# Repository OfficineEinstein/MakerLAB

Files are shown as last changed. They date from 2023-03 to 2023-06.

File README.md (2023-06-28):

# MakerLAB
Demo board didattica per i laboratori di Tecnologie e Progettazione di Sistemi Elettronici (TPSE):  elettronica digitale e microcontrollori
 
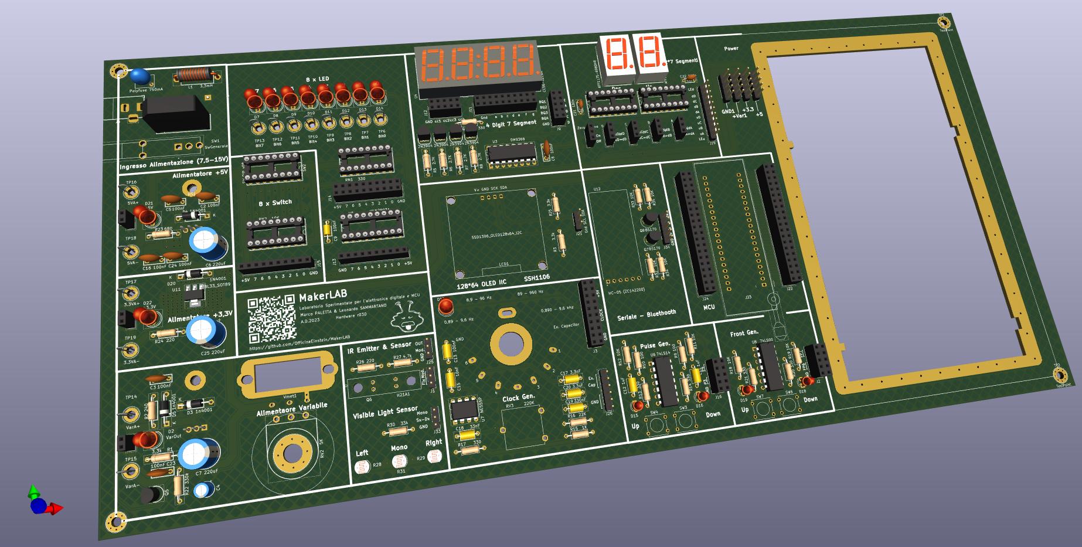
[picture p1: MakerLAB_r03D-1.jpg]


Il laboratorio portatile finalmente operativo
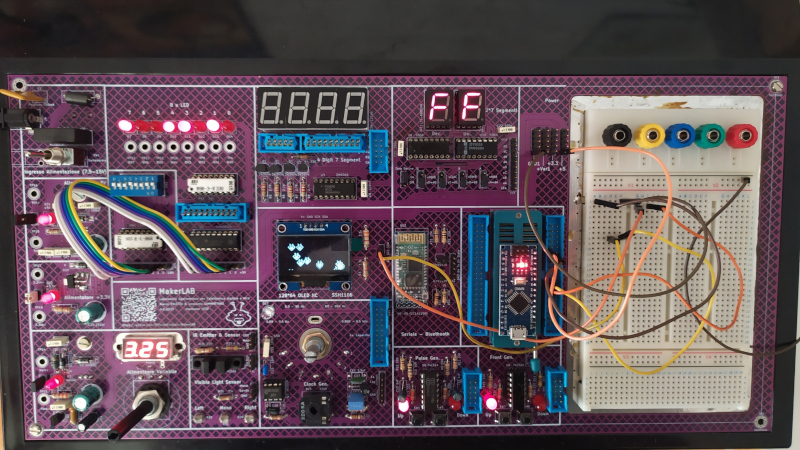
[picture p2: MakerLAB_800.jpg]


Video testing of the MakerLAB

[](https://www.youtube.com/watch?v=5uMLk8OzwR4 "videoprova shield")

https://youtu.be/5uMLk8OzwR4

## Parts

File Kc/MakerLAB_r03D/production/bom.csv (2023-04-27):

Designator | Footprint | Quantity | Value | LCSC Part #
+3.3, +5, +Var1, GND1, J34 | PinHeader_1x05_P2.54mm_Vertical | 5 | Conn_01x05
AFF1, AFF2 | 7SegmentLED_LTS6760_LTS6780 | 2 | LTS-6980HR
C1 | CP_Radial_D17.0mm_P7.50mm | 1 | 1000uF
C11, C12 | C_Axial_L5.1mm_D3.1mm_P7.50mm_Horizontal | 2 | 1uF
C13 | C_Axial_L5.1mm_D3.1mm_P7.50mm_Horizontal | 1 | 100nF
C15 | C_Axial_L5.1mm_D3.1mm_P7.50mm_Horizontal | 1 | 10nF
C16, C2, C23, C24, C3, C5 | C_Disc_D7.0mm_W2.5mm_P5.00mm | 6 | 100nF
C17 | C_Axial_L5.1mm_D3.1mm_P7.50mm_Horizontal | 1 | 3,3nF
C18 | C_Axial_L5.1mm_D3.1mm_P7.50mm_Horizontal | 1 | 33nF
C19 | C_Axial_L5.1mm_D3.1mm_P7.50mm_Horizontal | 1 | 330nF
C20 | C_Axial_L5.1mm_D3.1mm_P7.50mm_Horizontal | 1 | 3,3uF
C21, C22 | C_Disc_D4.3mm_W1.9mm_P5.00mm | 2 | 100n
C25, C6, C7 | CP_Radial_D10.0mm_P5.00mm | 3 | 220uF
C4 | CP_Radial_D5.0mm_P2.00mm | 1 | 10uF
C8 | C_Disc_D7.5mm_W2.5mm_P5.00mm | 1 | 100nF
C9 | C_Axial_L3.8mm_D2.6mm_P7.50mm_Horizontal | 1 | 100nF
D1 | Diode_Bridge_Vishay_KBL | 1 | D_Bridge_+AA-
D10 | LED_D5.0mm | 1 | 4
D11 | LED_D5.0mm | 1 | 3
D12 | LED_D5.0mm | 1 | 2
D13 | LED_D5.0mm | 1 | 1
D14 | LED_D5.0mm | 1 | 0
D15, D16, D18, D19 | LED_D3.0mm | 4 | LED
D17 | LED_D5.0mm | 1 | LED
D2 | LED_D5.0mm | 1 | VarOut
D20, D3, D4, D5 | D_A-405_P10.16mm_Horizontal | 4 | 1N4001
D21 | LED_D5.0mm | 1 | +5V
D22 | LED_D5.0mm | 1 | +3.3V
D7 | LED_D5.0mm | 1 | 7
D8 | LED_D5.0mm | 1 | 6
D9 | LED_D5.0mm | 1 | 5
F1 | RV_Disc_D7mm_W5.4mm_P5mm | 1 | Polyfuse 750mA
HS1, HS2 | Heatsink_28x25_Horiz | 2 | Heatsink
J1 | PinHeader_1x03_P2.54mm_Vertical | 1 | Fix
J11 | PinSocket_2x10_P2.54mm_Vertical | 1 | Gnd a b c d e f g
J12 | PinSocket_2x05_P2.54mm_Vertical | 1 | GND cc1 cc2
J13 | PinSocket_1x10_P2.54mm_Vertical | 1 | GND 7 6 5 4 3 2 1 0 +5V
J14 | PinSocket_2x10_P2.54mm_Vertical | 1 | +5V 7 6 5 4 3 2 1 0 GND
J15 | PinSocket_1x10_P2.54mm_Vertical | 1 | +5V 7 6 5 4 3 2 1 0 GND
J16 | PinSocket_2x05_P2.54mm_Vertical | 1 | P3 P4
J19 | PinHeader_1x10_P2.54mm_Vertical | 1 | LeU A0 A1 A2 A3 A0 A1 A2 A3 LeD
J2 | PinSocket_2x05_P2.54mm_Vertical | 1 | FP6 FP7
J21 | PinHeader_1x03_P2.54mm_Vertical | 1 | Gnd SCL SDA
J22, J24 | PinSocket_2x20_P2.54mm_Vertical | 2 | Conn_02x20_Counter_Clockwise
J23 | DIP_Socket-40_W22.1_W22.86_W25.4_W27.94_W28.7_3M_240-3639-00-0602J | 1 | 1
J25 | PinHeader_1x03_P2.54mm_Vertical | 1 | IR Emitter & Sensor
J26 | PinHeader_1x06_P2.54mm_Vertical | 1 | Conn_01x06_Female
J29, J30, J5 | PinSocket_1x02_P2.54mm_Vertical | 3 | Conn_01x02_Male
J3 | PinSocket_2x10_P2.54mm_Vertical | 1 | GND CLOCK +5V
J33 | PinHeader_1x03_P2.54mm_Vertical | 1 | Visible Light Sensor
J4 | BarrelJack_Horizontal | 1 | Barrel_Jack_MountingPin
J9 | PinSocket_2x05_P2.54mm_Vertical | 1 | A B C D LE
L1 | L_Axial_L12.0mm_D5.0mm_P15.24mm_Horizontal_Fastron_MISC | 1 | 3,3mH
LCD1 | TFT OLED 1.3 I2C | 1 | SSD1306_OLED128x64_I2C
Q1, Q2, Q3, Q4 | TO-92_Inline | 4 | 2N3904
Q5 | TO-92_Inline | 1 | BC237
Q6 | H21A1 | 1 | H21A1
Q7, Q8 | TO-92_Inline | 2 | BS170
R1, R25, R3 | R_Axial_DIN0207_L6.3mm_D2.5mm_P10.16mm_Horizontal | 3 | 3,3k
R10, R9 | R_Axial_DIN0207_L6.3mm_D2.5mm_P10.16mm_Horizontal | 2 | 100
R11, R12, R18, R19, R32, R33, R34, R35 | R_Axial_DIN0207_L6.3mm_D2.5mm_P10.16mm_Horizontal | 8 | 10K
R13, R14, R17, R20, R21, R4 | R_Axial_DIN0207_L6.3mm_D2.5mm_P10.16mm_Horizontal | 6 | 330
R15 | R_Axial_DIN0207_L6.3mm_D2.5mm_P10.16mm_Horizontal | 1 | 1K
R16 | R_Axial_DIN0207_L6.3mm_D2.5mm_P10.16mm_Horizontal | 1 | 22K
R2 | R_Axial_DIN0207_L6.3mm_D2.5mm_P10.16mm_Horizontal | 1 | 240
R22 | R_Axial_DIN0207_L6.3mm_D2.5mm_P10.16mm_Horizontal | 1 | 330k
R23 | R_Axial_DIN0207_L6.3mm_D2.5mm_P10.16mm_Horizontal | 1 | 680
R24, R26 | R_Axial_DIN0207_L6.3mm_D2.5mm_P10.16mm_Horizontal | 2 | 220
R27 | R_Axial_DIN0207_L6.3mm_D2.5mm_P10.16mm_Horizontal | 1 | 4,7k
R28 | R_LDR_5.0x4.1mm_P3mm_Vertical | 1 | Left
R29 | R_LDR_5.0x4.1mm_P3mm_Vertical | 1 | Right
R30 | R_Axial_DIN0207_L6.3mm_D2.5mm_P10.16mm_Horizontal | 1 | 33k
R31 | R_LDR_5.0x4.1mm_P3mm_Vertical | 1 | Mono
R5, R6, R7, R8 | R_Axial_DIN0207_L6.3mm_D2.5mm_P10.16mm_Horizontal | 4 | 2.7K
RN1 | DIP-16_W7.62mm_Socket_LongPads | 1 | 330
RN2 | DIP-16_W7.62mm_Socket_LongPads | 1 | 10K
RV2 | Potentiometer_Omeg_PC16BU_Vertical | 1 | 5K
RV3 | Potentiometer_ACP_CA14V-15_Vertical | 1 | 220K
SW1 | SW_100SP1T2B4M7QE | 1 | SwGenerale
SW2 | DIP-16_W7.62mm_Socket_LongPads | 1 | SW_DIP_x08
SW3, SW6 | SW_Tactile_Straight_KSL0Axx1LFTR | 2 | Down
SW4, SW7 | SW_Tactile_Straight_KSL0Axx1LFTR | 2 | Up
SW5 | Commutatore 2x6 | 1 | SW_Rotary12
TP1, TP2, TP3, TP4 | MountingHole_3.2mm_M3_Pad_Via | 4 | TestPoint
TP10 | TestPoint_Loop_D3.80mm_Drill2.8mm | 1 | Bit4
TP11 | TestPoint_Loop_D3.80mm_Drill2.8mm | 1 | Bit5
TP12 | TestPoint_Loop_D3.80mm_Drill2.8mm | 1 | Bit6
TP13 | TestPoint_Loop_D3.80mm_Drill2.8mm | 1 | Bit7
TP14 | TestPoint_Loop_D3.80mm_Drill2.8mm | 1 | VarA+
TP15 | TestPoint_Loop_D3.80mm_Drill2.8mm | 1 | VarA-
TP16 | TestPoint_Loop_D3.80mm_Drill2.8mm | 1 | 5VA+
TP17 | TestPoint_Loop_D3.80mm_Drill2.8mm | 1 | 3.3VA+
TP18 | TestPoint_Loop_D3.80mm_Drill2.8mm | 1 | 5VA-
TP19 | TestPoint_Loop_D3.80mm_Drill2.8mm | 1 | 3.3VA-
TP20 | MountingHole_6.5mm_Pad_Via | 1 | Potenziometer
TP21 | Alimentatore Variabile | 1 | Alimentaore Variabile
TP22 | Alimentatore Variabile | 1 | Alimentatore +3,3V
TP23 | Alimentatore Variabile | 1 | Alimentatore +5V
TP24 | Alimentatore Variabile | 1 | Ingresso Alimentazione (7,5-15V)
TP25 | Alimentatore Variabile | 1 | 8 x Switch
TP26 | Alimentatore Variabile | 1 | 8 x LED
TP27 | Disp4x7Seg | 1 | 8 x LED
TP28 | MakerLABTitoli | 1 | MakerLAB
TP29 | Clock NE555 | 1 | Clock Gen.
TP31, TP32, TP35 | Disp4x7Seg | 3 | Pulse Generator
TP34 | Disp4x7Seg | 1 | 2*7 Segmenti
TP5 | BreadBoard 81x146 | 1 | TestPoint
TP6 | TestPoint_Loop_D3.80mm_Drill2.8mm | 1 | Bit0
TP7 | TestPoint_Loop_D3.80mm_Drill2.8mm | 1 | Bit1
TP8 | TestPoint_Loop_D3.80mm_Drill2.8mm | 1 | Bit2
TP9 | TestPoint_Loop_D3.80mm_Drill2.8mm | 1 | Bit3
U1 | TO-220-3_Horizontal_TabDown | 1 | LM317_TO-220
U10, U9 | DIP-16_W7.62mm_Socket_LongPads | 2 | 9368
U11 | SOT-223 | 1 | L78L33_SOT89
U12 | HC-05 Module Horizontal (ZC14200) | 1 | HC-05 (ZC142200)
U2 | TO-220-3_Horizontal_TabDown | 1 | LM7805_TO220
U3 | DIP-16_W7.62mm_LongPads | 1 | DM9368
U4 | CA56-12EWA | 1 | CC56-12EWA
U5 | DIP-18_W7.62mm_Socket_LongPads | 1 | ULN2803A
U6 | DIP-14_W7.62mm | 1 | 74LS14
U7 | DIP-8_W7.62mm | 1 | NE555P
U8 | DIP-14_W7.62mm | 1 | 74LS00
Uni-A0, Uni-A1, Uni-A2, Uni-A3 | PinSocket_1x03_P2.54mm_Vertical | 4 | Jumper_3_Open
Uni-A4 | PinSocket_1x03_P2.54mm_Vertical | 1 | Zero Decine
Vmet1 | 3,5 Digit 0,28'' Voltmeter | 1 | 3,5_Digit_Voltmeter_3Wire

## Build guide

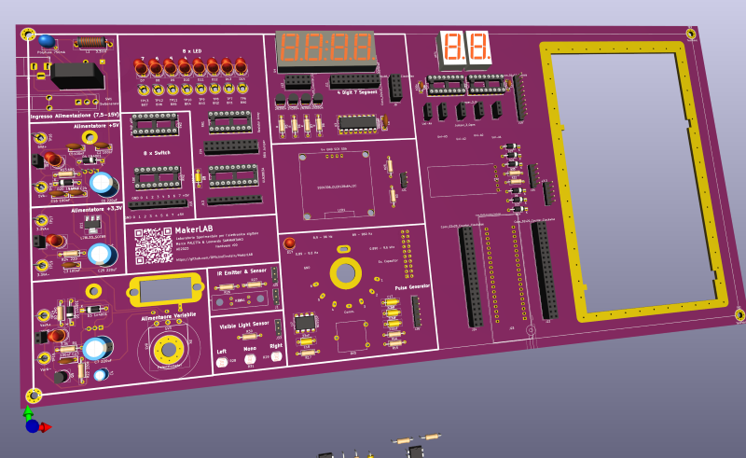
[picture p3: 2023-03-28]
MakerLAB_800.png

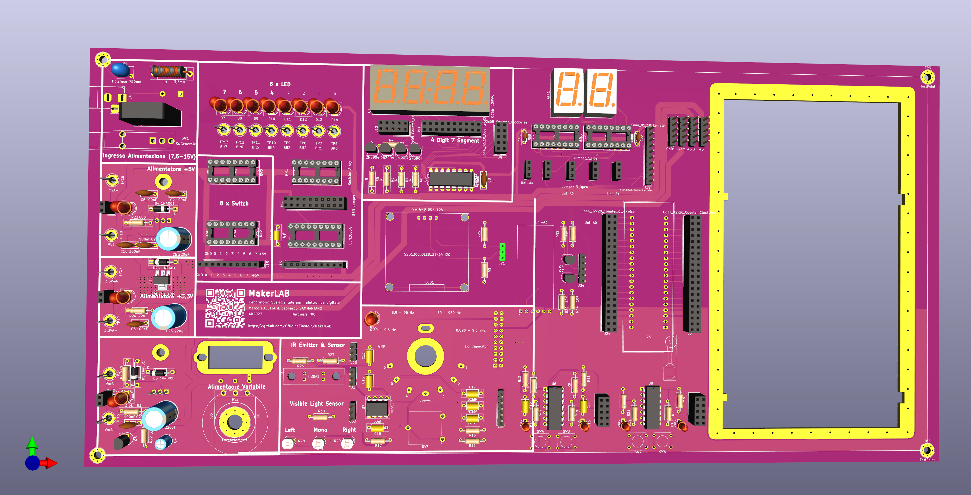
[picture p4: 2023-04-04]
Kc/MakerLAB_r03D1/MakerLAB_r03D1.png

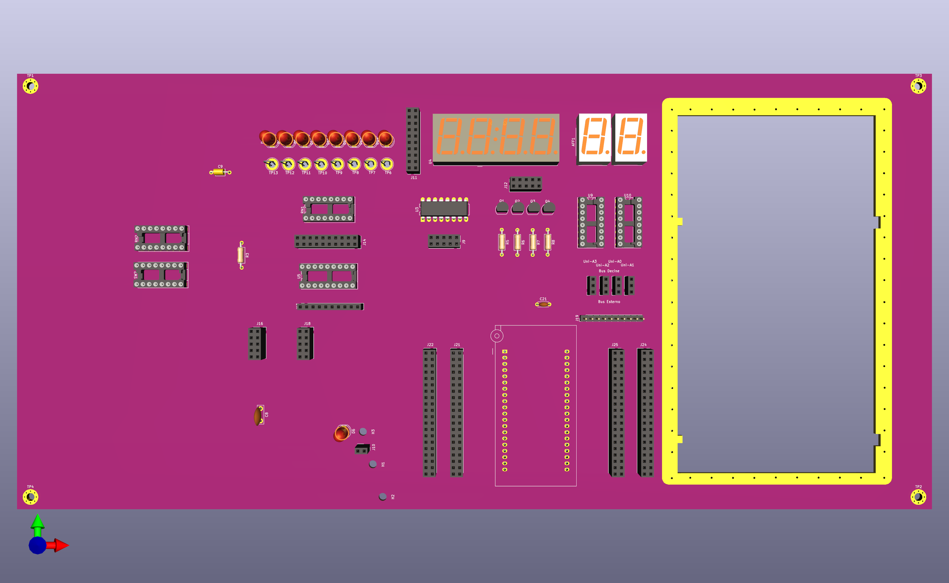
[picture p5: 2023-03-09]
Kc/MakerLAB_r03D1/MakerLab_r02-Incoming00.png

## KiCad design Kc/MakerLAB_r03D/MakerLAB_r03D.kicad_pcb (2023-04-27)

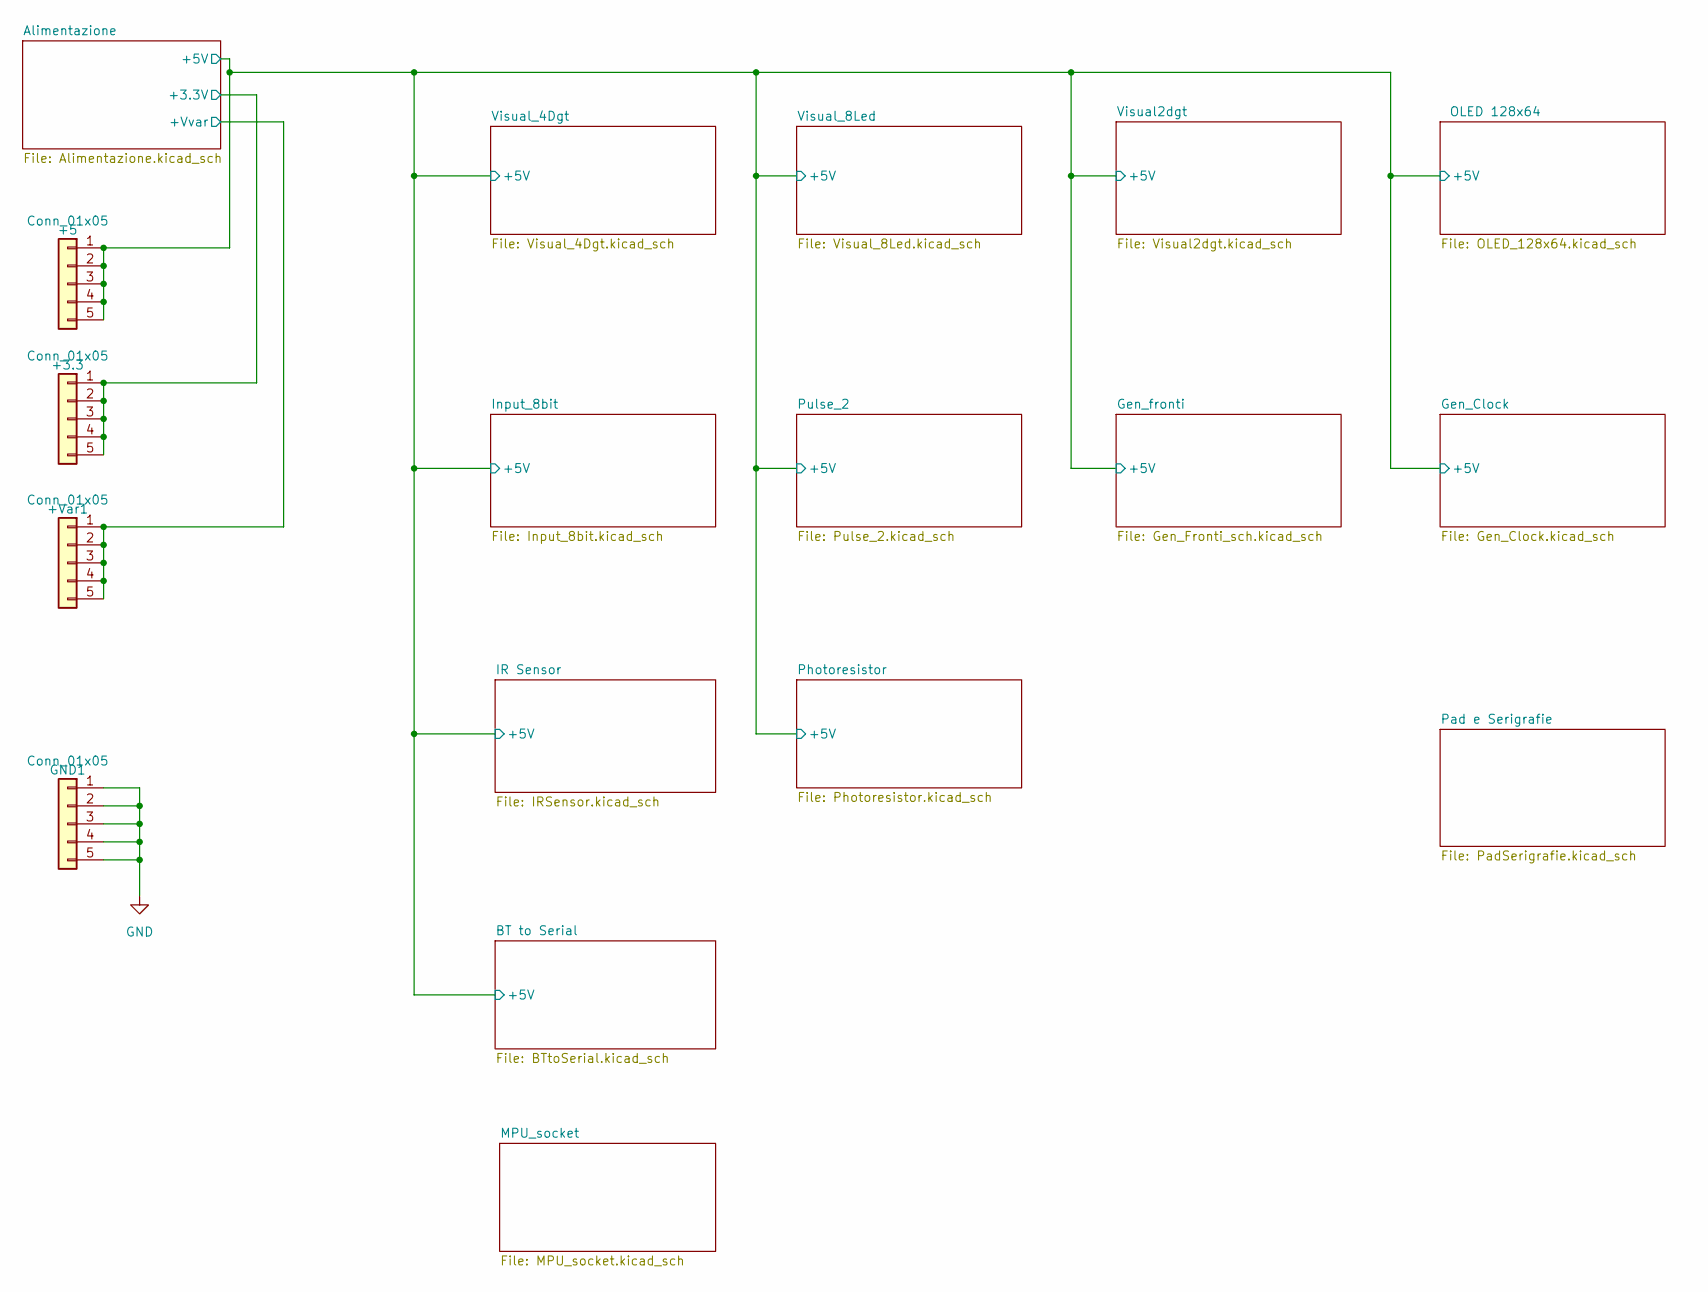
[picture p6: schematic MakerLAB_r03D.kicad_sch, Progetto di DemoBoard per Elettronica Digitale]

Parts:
+3.3, +5: Conn_01x05; PinHeader_1x05_P2.54mm_Vertical
+Var1: Conn_01x05; PinHeader_1x05_P2.54mm_Vertical
GND1: Conn_01x05; PinHeader_1x05_P2.54mm_Vertical

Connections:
/Alimentazione/+3.3V: +3.3.1, +3.3.2, +3.3.3, +3.3.4, +3.3.5; also elsewhere on the board
/Alimentazione/+5V: +5.1, +5.2, +5.3, +5.4, +5.5; also elsewhere on the board
/Alimentazione/+Vvar: +Var1.1, +Var1.2, +Var1.3, +Var1.4, +Var1.5; also elsewhere on the board

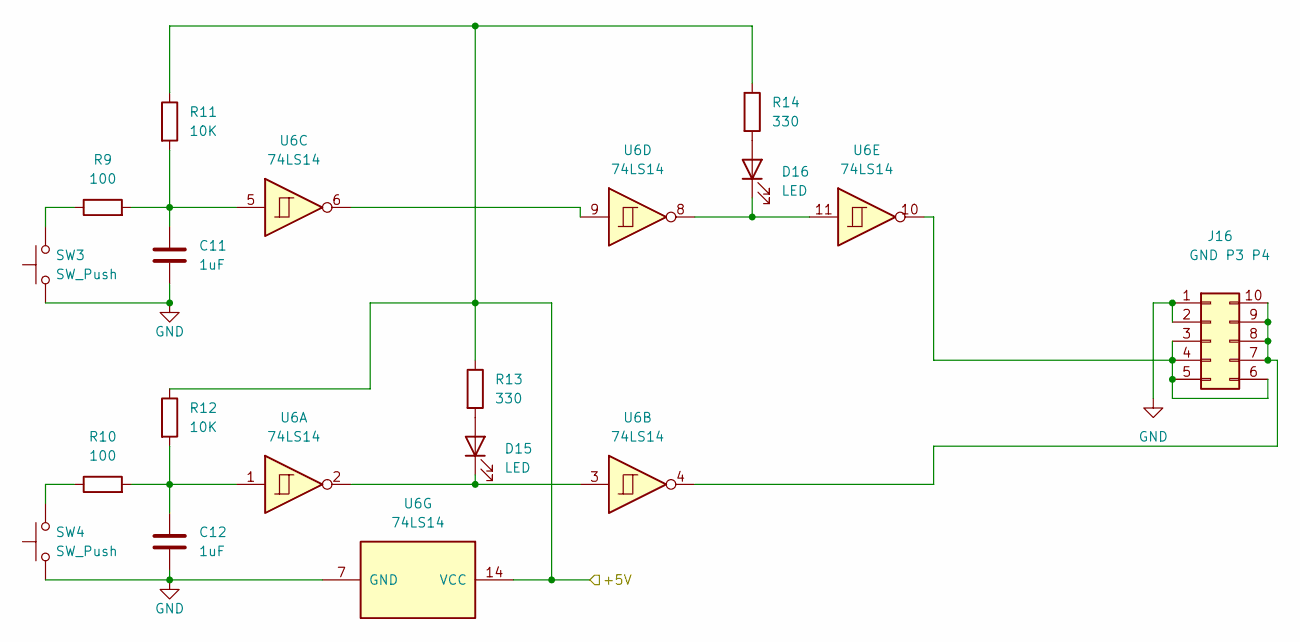
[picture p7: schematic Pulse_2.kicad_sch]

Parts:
C11, C12: 1uF; C_Axial_L5.1mm_D3.1mm_P7.50mm_Horizontal
D15, D16: LED; LED_D3.0mm
J16: GND P3 P4; PinSocket_2x05_P2.54mm_Vertical
R9, R10: 100; R_Axial_DIN0207_L6.3mm_D2.5mm_P10.16mm_Horizontal
R11, R12: 10K; R_Axial_DIN0207_L6.3mm_D2.5mm_P10.16mm_Horizontal
R13, R14: 330; R_Axial_DIN0207_L6.3mm_D2.5mm_P10.16mm_Horizontal
SW3, SW4: SW_Push; SW_Tactile_Straight_KSL0Axx1LFTR
U6: 74LS14; DIP-14_W7.62mm

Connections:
/Alimentazione/+5V: R11.1, R12.1, R13.1, R14.1, U6.14 (VCC); also elsewhere on the board
unnamed: C11.1, R9.2, R11.2, U6.5
unnamed: C12.1, R10.2, R12.2, U6.1
unnamed: D15.1 (K), U6.2, U6.3
unnamed: D15.2 (A), R13.2
unnamed: D16.1 (K), U6.8, U6.11
unnamed: D16.2 (A), R14.2
unnamed: J16.3, J16.4, J16.5, J16.6, U6.10
unnamed: J16.7, J16.8, J16.9, J16.10, U6.4
unnamed: R9.1, SW3.2
unnamed: R10.1, SW4.2
unnamed: U6.6, U6.9

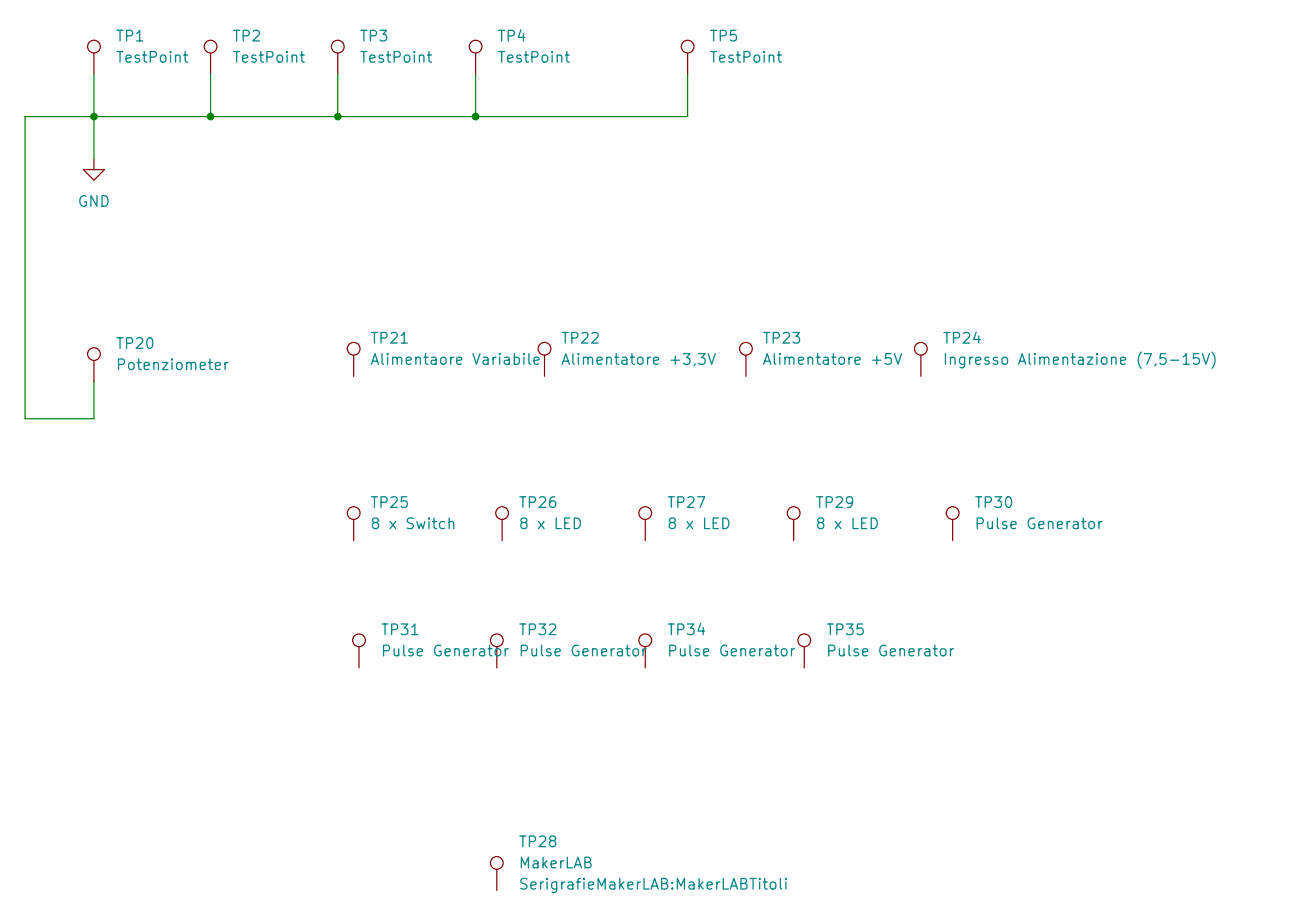
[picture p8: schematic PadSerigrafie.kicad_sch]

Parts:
TP1, TP2, TP3, TP4: TestPoint; MountingHole_3.2mm_M3_Pad_Via
TP5: TestPoint; BreadBoard 81x146
TP20: Potenziometer; MountingHole_6.5mm_Pad_Via
TP21: Alimentaore Variabile; Alimentatore Variabile
TP22: Alimentatore +3,3V; Alimentatore Variabile
TP23: Alimentatore +5V; Alimentatore Variabile
TP24: Ingresso Alimentazione (7,5-15V); Alimentatore Variabile
TP25: 8 x Switch; Alimentatore Variabile
TP26: 8 x LED; Alimentatore Variabile
TP27: 8 x LED; Disp4x7Seg
TP28: MakerLAB; MakerLABTitoli
TP29: 8 x LED; Clock NE555
TP30: Pulse Generator; Clock NE555
TP31, TP32, TP34, TP35: Pulse Generator; Disp4x7Seg

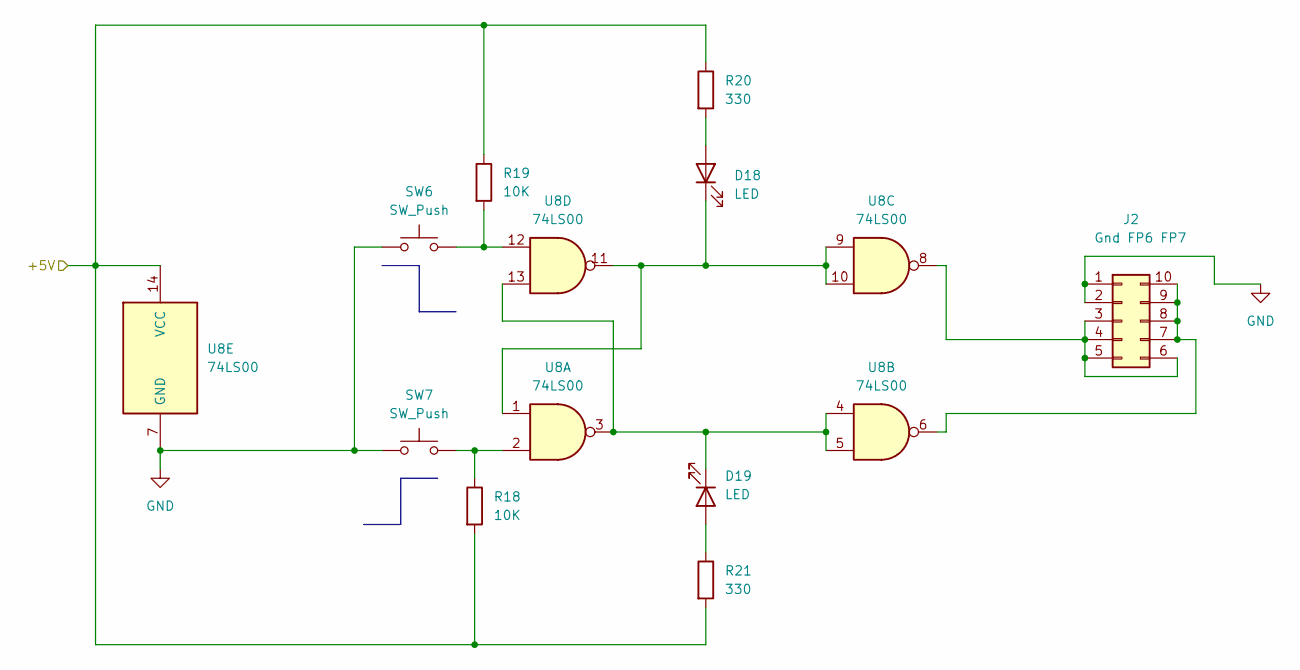
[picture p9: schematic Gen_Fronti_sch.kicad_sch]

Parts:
D18, D19: LED; LED_D3.0mm
J2: Gnd FP6 FP7; PinSocket_2x05_P2.54mm_Vertical
R18, R19: 10K; R_Axial_DIN0207_L6.3mm_D2.5mm_P10.16mm_Horizontal
R20, R21: 330; R_Axial_DIN0207_L6.3mm_D2.5mm_P10.16mm_Horizontal
SW6, SW7: SW_Push; SW_Tactile_Straight_KSL0Axx1LFTR
U8: 74LS00; DIP-14_W7.62mm

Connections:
/Alimentazione/+5V: R18.2, R19.1, R20.1, R21.2, U8.14 (VCC); also elsewhere on the board
unnamed: D18.1 (K), U8.1, U8.9, U8.10, U8.11
unnamed: D18.2 (A), R20.2
unnamed: D19.1 (K), U8.3, U8.4, U8.5, U8.13
unnamed: D19.2 (A), R21.1
unnamed: J2.3, J2.4, J2.5, J2.6, U8.8
unnamed: J2.7, J2.8, J2.9, J2.10, U8.6
unnamed: R18.1, SW7.2, U8.2
unnamed: R19.2, SW6.2, U8.12

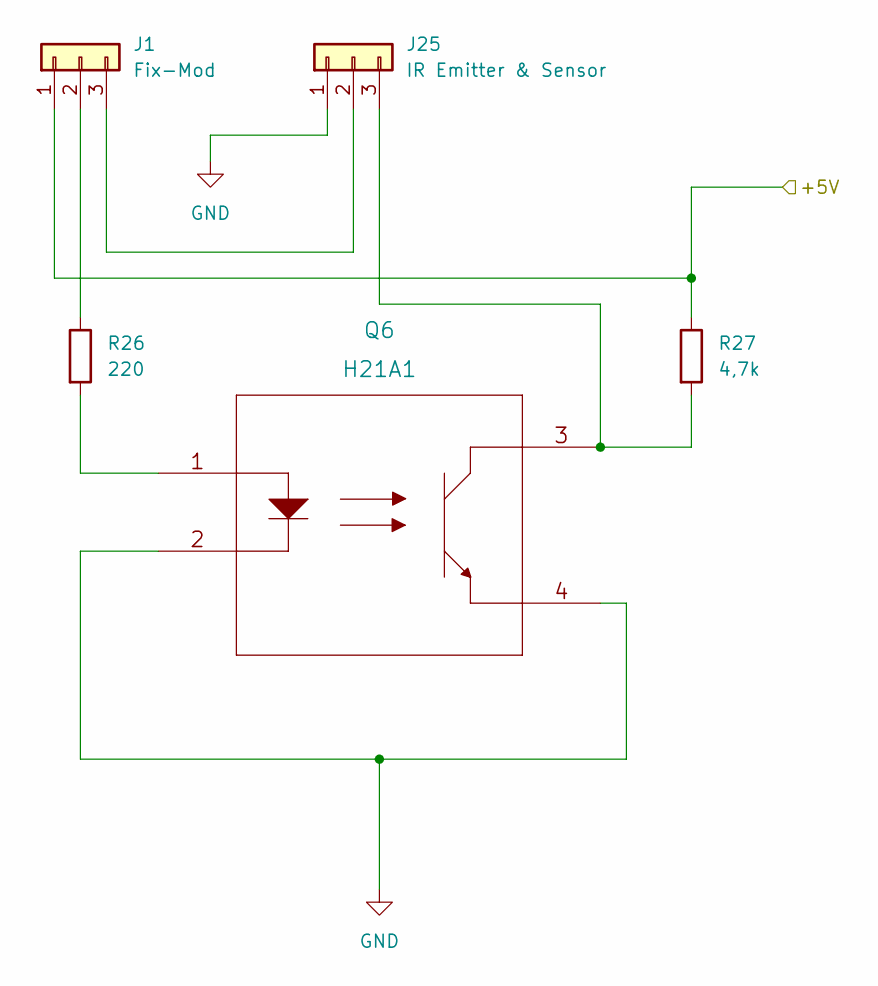
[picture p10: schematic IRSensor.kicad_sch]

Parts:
J1: Fix-Mod; PinHeader_1x03_P2.54mm_Vertical
J25: IR Emitter & Sensor; PinHeader_1x03_P2.54mm_Vertical
Q6: H21A1
R26: 220; R_Axial_DIN0207_L6.3mm_D2.5mm_P10.16mm_Horizontal
R27: 4,7k; R_Axial_DIN0207_L6.3mm_D2.5mm_P10.16mm_Horizontal

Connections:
/Alimentazione/+5V: J1.1, R27.1; also elsewhere on the board
unnamed: J1.2, R26.1
unnamed: J1.3, J25.2
unnamed: J25.3, Q6.3, R27.2
unnamed: Q6.1, R26.2

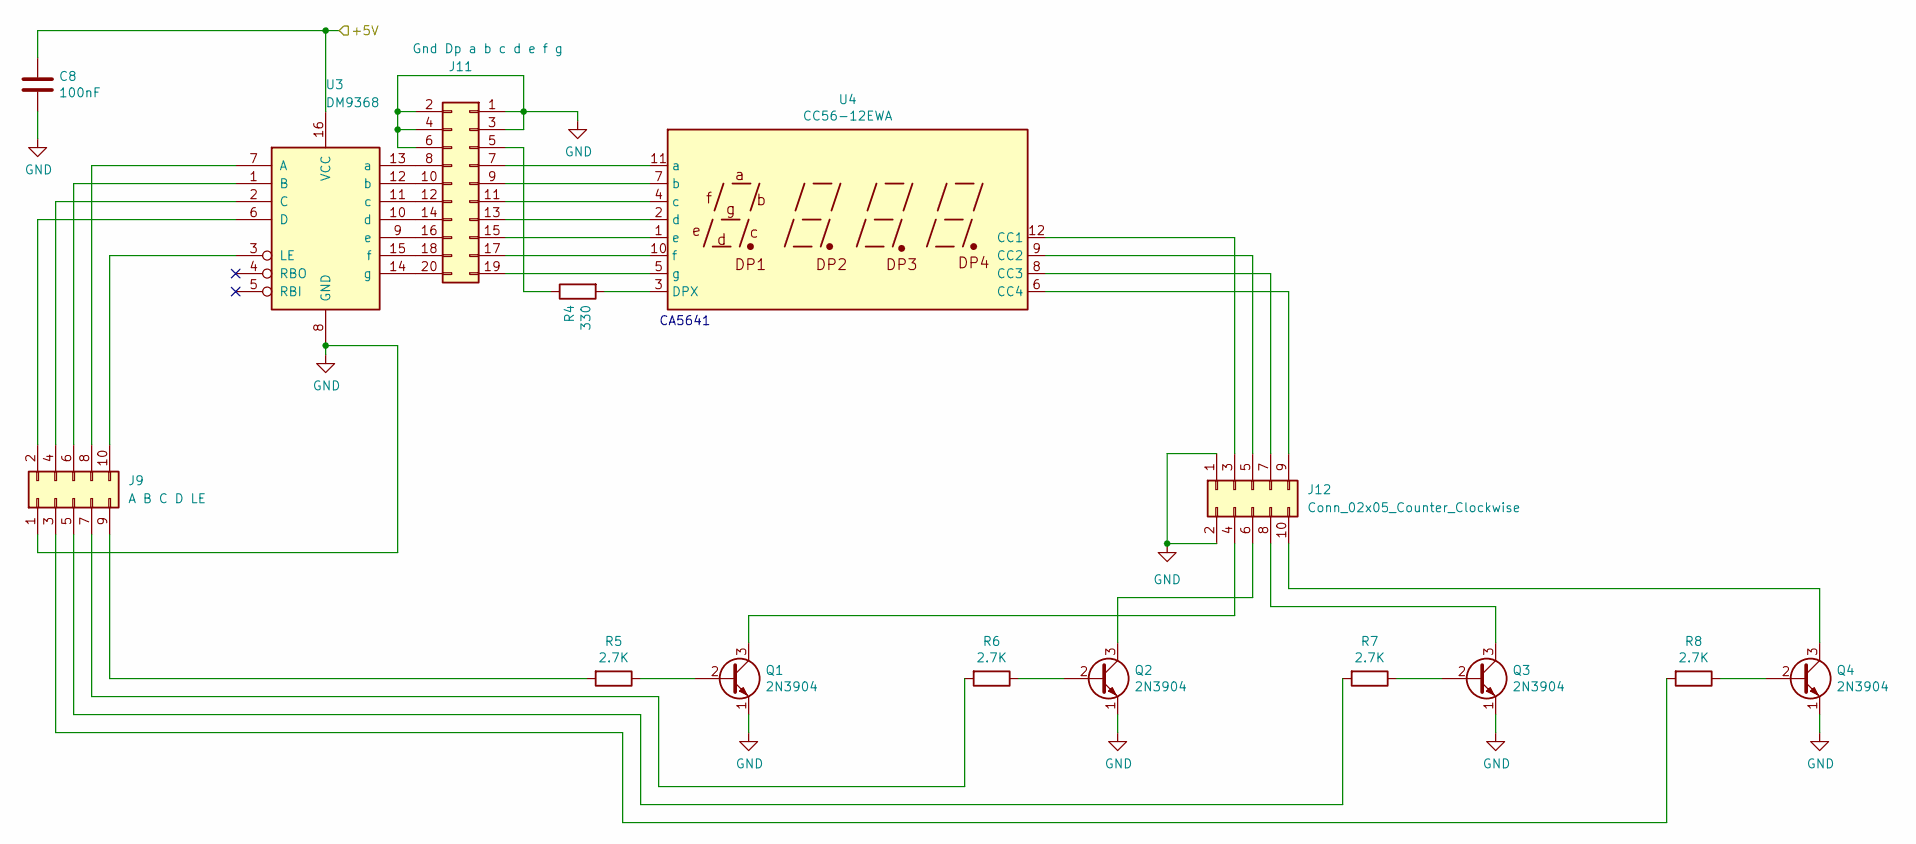
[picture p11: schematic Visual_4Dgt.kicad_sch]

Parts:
C8: 100nF; C_Disc_D7.5mm_W2.5mm_P5.00mm
J9: A B C D LE; PinSocket_2x05_P2.54mm_Vertical
J11: Gnd Dp a b c d e f g; PinSocket_2x10_P2.54mm_Vertical
J12: Conn_02x05_Counter_Clockwise; PinSocket_2x05_P2.54mm_Vertical
Q1, Q2, Q3, Q4: 2N3904; TO-92_Inline
R4: 330; R_Axial_DIN0207_L6.3mm_D2.5mm_P10.16mm_Horizontal
R5, R6, R7, R8: 2.7K; R_Axial_DIN0207_L6.3mm_D2.5mm_P10.16mm_Horizontal
U3: DM9368; DIP-16_W7.62mm_LongPads
U4: CC56-12EWA; CA56-12EWA

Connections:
/Alimentazione/+5V: C8.1, U3.16 (VCC); also elsewhere on the board
unnamed: J9.2, U3.6 (D)
unnamed: J9.3, R8.2
unnamed: J9.4, U3.2 (C)
unnamed: J9.5, R7.2
unnamed: J9.6, U3.1 (B)
unnamed: J9.7, R6.2
unnamed: J9.8, U3.7 (A)
unnamed: J9.9, R5.2
unnamed: J9.10, U3.3 (LE)
unnamed: J11.5, R4.1
unnamed: J11.7, U4.11 (a)
unnamed: J11.8, U3.13 (a)
unnamed: J11.9, U4.7 (b)
unnamed: J11.10, U3.12 (b)
unnamed: J11.11, U4.4 (c)
unnamed: J11.12, U3.11 (c)
unnamed: J11.13, U4.2 (d)
unnamed: J11.14, U3.10 (d)
unnamed: J11.15, U4.1 (e)
unnamed: J11.16, U3.9 (e)
unnamed: J11.17, U4.10 (f)
unnamed: J11.18, U3.15 (f)
unnamed: J11.19, U4.5 (g)
unnamed: J11.20, U3.14 (g)
unnamed: J12.3, U4.12 (CC1)
unnamed: J12.4, Q1.3 (C)
unnamed: J12.5, U4.9 (CC2)
unnamed: J12.6, Q2.3 (C)
unnamed: J12.7, U4.8 (CC3)
unnamed: J12.8, Q3.3 (C)
unnamed: J12.9, U4.6 (CC4)
unnamed: J12.10, Q4.3 (C)
unnamed: Q1.2 (B), R5.1
unnamed: Q2.2 (B), R6.1
unnamed: Q3.2 (B), R7.1
unnamed: Q4.2 (B), R8.1
unnamed: R4.2, U4.3 (DPX)

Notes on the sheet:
CA5641

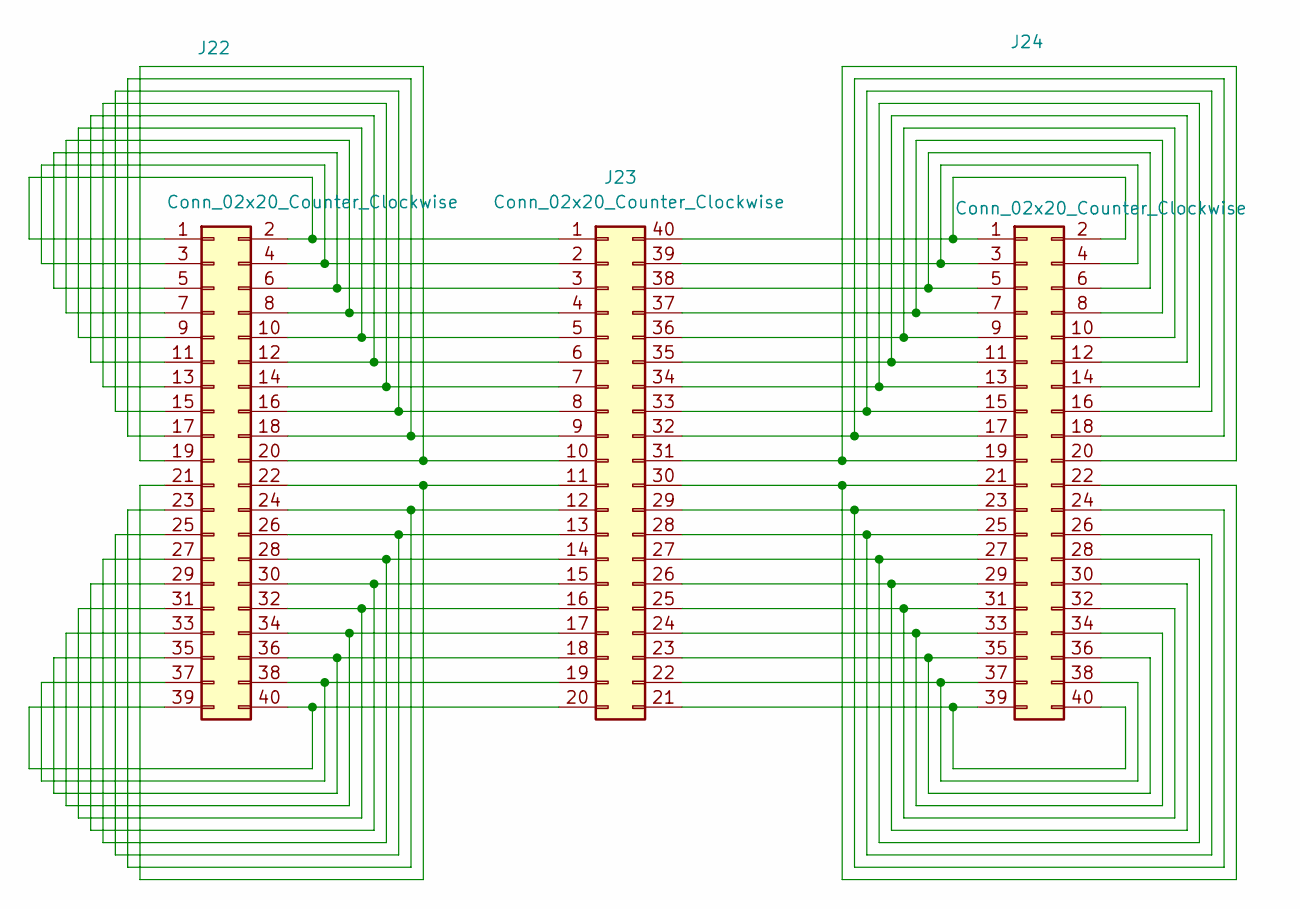
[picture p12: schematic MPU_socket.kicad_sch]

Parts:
J22, J24: Conn_02x20_Counter_Clockwise; PinSocket_2x20_P2.54mm_Vertical
J23: Conn_02x20_Counter_Clockwise; DIP_Socket-40_W22.1_W22.86_W25.4_W27.94_W28.7_3M_240-3639-0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

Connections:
unnamed: J22.1, J22.2, J23.1
unnamed: J22.3, J22.4, J23.2
unnamed: J22.5, J22.6, J23.3
unnamed: J22.7, J22.8, J23.4
unnamed: J22.9, J22.10, J23.5
unnamed: J22.11, J22.12, J23.6
unnamed: J22.13, J22.14, J23.7
unnamed: J22.15, J22.16, J23.8
unnamed: J22.17, J22.18, J23.9
unnamed: J22.19, J22.20, J23.10
unnamed: J22.21, J22.22, J23.11
unnamed: J22.23, J22.24, J23.12
unnamed: J22.25, J22.26, J23.13
unnamed: J22.27, J22.28, J23.14
unnamed: J22.29, J22.30, J23.15
unnamed: J22.31, J22.32, J23.16
unnamed: J22.33, J22.34, J23.17
unnamed: J22.35, J22.36, J23.18
unnamed: J22.37, J22.38, J23.19
unnamed: J22.39, J22.40, J23.20
unnamed: J23.21, J24.39, J24.40
unnamed: J23.22, J24.37, J24.38
unnamed: J23.23, J24.35, J24.36
unnamed: J23.24, J24.33, J24.34
unnamed: J23.25, J24.31, J24.32
unnamed: J23.26, J24.29, J24.30
unnamed: J23.27, J24.27, J24.28
unnamed: J23.28, J24.25, J24.26
unnamed: J23.29, J24.23, J24.24
unnamed: J23.30, J24.21, J24.22
unnamed: J23.31, J24.19, J24.20
unnamed: J23.32, J24.17, J24.18
unnamed: J23.33, J24.15, J24.16
unnamed: J23.34, J24.13, J24.14
unnamed: J23.35, J24.11, J24.12
unnamed: J23.36, J24.9, J24.10
unnamed: J23.37, J24.7, J24.8
unnamed: J23.38, J24.5, J24.6
unnamed: J23.39, J24.3, J24.4
unnamed: J23.40, J24.1, J24.2

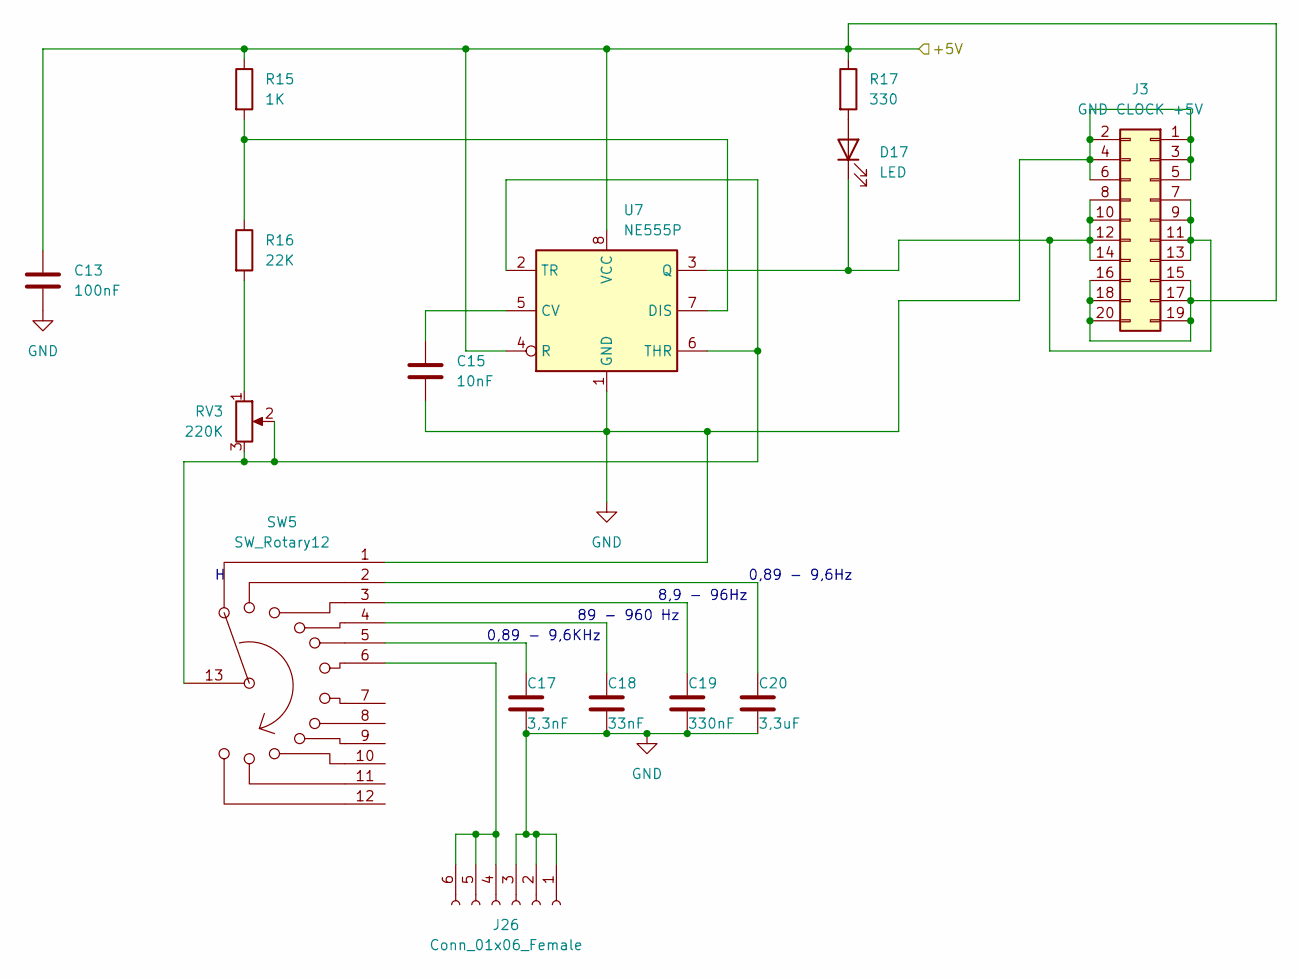
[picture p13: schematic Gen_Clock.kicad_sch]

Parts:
C13: 100nF; C_Axial_L5.1mm_D3.1mm_P7.50mm_Horizontal
C15: 10nF; C_Axial_L5.1mm_D3.1mm_P7.50mm_Horizontal
C17: 3,3nF; C_Axial_L5.1mm_D3.1mm_P7.50mm_Horizontal
C18: 33nF; C_Axial_L5.1mm_D3.1mm_P7.50mm_Horizontal
C19: 330nF; C_Axial_L5.1mm_D3.1mm_P7.50mm_Horizontal
C20: 3,3uF; C_Axial_L5.1mm_D3.1mm_P7.50mm_Horizontal
D17: LED; LED_D5.0mm
J3: GND CLOCK +5V; PinSocket_2x10_P2.54mm_Vertical
J26: Conn_01x06_Female; PinHeader_1x06_P2.54mm_Vertical
R15: 1K; R_Axial_DIN0207_L6.3mm_D2.5mm_P10.16mm_Horizontal
R16: 22K; R_Axial_DIN0207_L6.3mm_D2.5mm_P10.16mm_Horizontal
R17: 330; R_Axial_DIN0207_L6.3mm_D2.5mm_P10.16mm_Horizontal
RV3: 220K; Potentiometer_ACP_CA14V-15_Vertical
SW5: SW_Rotary12; Commutatore 2x6
U7: NE555P; DIP-8_W7.62mm

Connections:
/Alimentazione/+5V: C13.1, J3.15, J3.16, J3.17, J3.18, J3.19, J3.20, R15.1, R17.1, U7.4 (R), U7.8 (VCC); also elsewhere on the board
unnamed: C15.1, U7.5 (CV)
unnamed: C17.1, SW5.5
unnamed: C18.1, SW5.4
unnamed: C19.1, SW5.3
unnamed: C20.1, SW5.2
unnamed: D17.1 (K), J3.7, J3.8, J3.9, J3.10, J3.11, J3.12, J3.13, J3.14, U7.3 (Q)
unnamed: D17.2 (A), R17.2
unnamed: J26.4, J26.5, J26.6, SW5.6
unnamed: R15.2, R16.1, U7.7 (DIS)
unnamed: R16.2, RV3.1
unnamed: RV3.2, RV3.3, SW5.13, U7.2 (TR), U7.6 (THR)

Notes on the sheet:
0,89 - 9,6Hz
0,89 - 9,6KHz
8,9 - 96Hz
89 - 960 Hz

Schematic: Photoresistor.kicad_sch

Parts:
J33: Visible Light Sensor; PinHeader_1x03_P2.54mm_Vertical
R28: Left; R_LDR_5.0x4.1mm_P3mm_Vertical
R29: Right; R_LDR_5.0x4.1mm_P3mm_Vertical
R30: 33k; R_Axial_DIN0207_L6.3mm_D2.5mm_P10.16mm_Horizontal
R31: Mono; R_LDR_5.0x4.1mm_P3mm_Vertical

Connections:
/Alimentazione/+5V: R28.1, R30.1; also elsewhere on the board
unnamed: J33.2, R28.2, R29.1
unnamed: J33.3, R30.2, R31.1

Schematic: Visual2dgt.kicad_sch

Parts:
AFF1, AFF2: LTS-6980HR; 7SegmentLED_LTS6760_LTS6780
C21, C22: 100n; C_Disc_D4.3mm_W1.9mm_P5.00mm
J19: LE A0 A1 A2 A3 A0 A1 A2 A3 LE; PinHeader_1x10_P2.54mm_Vertical
U9, U10: 9368; DIP-16_W7.62mm_Socket_LongPads
Uni-A0, Uni-A1, Uni-A2, Uni-A3, Uni-A4: Jumper_3_Open; PinSocket_1x03_P2.54mm_Vertical

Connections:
/Alimentazione/+5V: C21.1, C22.1, U9.16 (Vcc), U10.16 (Vcc); also elsewhere on the board
unnamed: AFF1.1 (e), U9.9 (e)
unnamed: AFF1.2 (d), U9.10 (d)
unnamed: AFF1.4 (c), U9.11 (c)
unnamed: AFF1.6 (b), U9.12 (b)
unnamed: AFF1.7 (a), U9.13 (a)
unnamed: AFF1.9 (f), U9.15 (f)
unnamed: AFF1.10 (g), U9.14 (g)
unnamed: AFF2.1 (e), U10.9 (e)
unnamed: AFF2.2 (d), U10.10 (d)
unnamed: AFF2.4 (c), U10.11 (c)
unnamed: AFF2.6 (b), U10.12 (b)
unnamed: AFF2.7 (a), U10.13 (a)
unnamed: AFF2.9 (f), U10.15 (f)
unnamed: AFF2.10 (g), U10.14 (g)
unnamed: J19.1, U10.3 (LE-)
unnamed: J19.2, Uni-A0.1 (A)
unnamed: J19.3, Uni-A1.1 (A)
unnamed: J19.4, Uni-A2.1 (A)
unnamed: J19.5, Uni-A3.1 (A)
unnamed: J19.6, U9.7 (A0), Uni-A0.3 (B)
unnamed: J19.7, U9.1 (A1), Uni-A1.3 (B)
unnamed: J19.8, U9.2 (A2), Uni-A2.3 (B)
unnamed: J19.9, U9.6 (A3), Uni-A3.3 (B)
unnamed: J19.10, U9.3 (LE-)
unnamed: U9.5 (RBI-), Uni-A4.2 (C)
unnamed: U10.1 (A1), Uni-A1.2 (C)
unnamed: U10.2 (A2), Uni-A2.2 (C)
unnamed: U9.4 (RBO-), U10.5 (RBI-)
unnamed: U10.6 (A3), Uni-A3.2 (C)
unnamed: U10.7 (A0), Uni-A0.2 (C)

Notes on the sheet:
unità
decine
Rbo_Off

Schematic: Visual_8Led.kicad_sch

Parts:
C9: 100nF; C_Axial_L3.8mm_D2.6mm_P7.50mm_Horizontal
D7: 7; LED_D5.0mm
D8: 6; LED_D5.0mm
D9: 5; LED_D5.0mm
D10: 4; LED_D5.0mm
D11: 3; LED_D5.0mm
D12: 2; LED_D5.0mm
D13: 1; LED_D5.0mm
D14: 0; LED_D5.0mm
J13: GND 0 1 2 3 4 5 6 7 +5V; PinSocket_1x10_P2.54mm_Vertical
J14: 8Bit Jumper; PinSocket_2x10_P2.54mm_Vertical
RN1: 330; DIP-16_W7.62mm_Socket_LongPads
TP6: Bit0; TestPoint_Loop_D3.80mm_Drill2.8mm
TP7: Bit1; TestPoint_Loop_D3.80mm_Drill2.8mm
TP8: Bit2; TestPoint_Loop_D3.80mm_Drill2.8mm
TP9: Bit3; TestPoint_Loop_D3.80mm_Drill2.8mm
TP10: Bit4; TestPoint_Loop_D3.80mm_Drill2.8mm
TP11: Bit5; TestPoint_Loop_D3.80mm_Drill2.8mm
TP12: Bit6; TestPoint_Loop_D3.80mm_Drill2.8mm
TP13: Bit7; TestPoint_Loop_D3.80mm_Drill2.8mm
U5: ULN2803A; DIP-18_W7.62mm_Socket_LongPads

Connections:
/Alimentazione/+5V: C9.2, D7.2 (A), D8.2 (A), D9.2 (A), D10.2 (A), D11.2 (A), D12.2 (A), D13.2 (A), D14.2 (A), J13.10, J14.20; also elsewhere on the board
unnamed: D7.1 (K), RN1.16 (R1.2), TP13.1
unnamed: D8.1 (K), RN1.15 (R2.2), TP12.1
unnamed: D9.1 (K), RN1.14 (R3.2), TP11.1
unnamed: D10.1 (K), RN1.13 (R4.2), TP10.1
unnamed: D11.1 (K), RN1.12 (R5.2), TP9.1
unnamed: D12.1 (K), RN1.11 (R6.2), TP8.1
unnamed: D13.1 (K), RN1.10 (R7.2), TP7.1
unnamed: D14.1 (K), RN1.9 (R8.2), TP6.1
unnamed: J13.2, U5.1 (I1)
unnamed: J13.3, U5.2 (I2)
unnamed: J13.4, U5.3 (I3)
unnamed: J13.5, U5.4 (I4)
unnamed: J13.6, U5.5 (I5)
unnamed: J13.7, U5.6 (I6)
unnamed: J13.8, U5.7 (I7)
unnamed: J13.9, U5.8 (I8)
unnamed: J14.3, U5.11 (O8)
unnamed: J14.4, RN1.8 (R8.1)
unnamed: J14.5, U5.12 (O7)
unnamed: J14.6, RN1.7 (R7.1)
unnamed: J14.7, U5.13 (O6)
unnamed: J14.8, RN1.6 (R6.1)
unnamed: J14.9, U5.14 (O5)
unnamed: J14.10, RN1.5 (R5.1)
unnamed: J14.11, U5.15 (O4)
unnamed: J14.12, RN1.4 (R4.1)
unnamed: J14.13, U5.16 (O3)
unnamed: J14.14, RN1.3 (R3.1)
unnamed: J14.15, U5.17 (O2)
unnamed: J14.16, RN1.2 (R2.1)
unnamed: J14.17, U5.18 (O1)
unnamed: J14.18, RN1.1 (R1.1)
unnamed: J14.19, U5.10 (COM)

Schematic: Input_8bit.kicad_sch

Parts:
J15: GND 0 1 2 3 4 5 6 7 +5V; PinSocket_1x10_P2.54mm_Vertical
RN2: 10K; DIP-16_W7.62mm_Socket_LongPads
SW2: SW_DIP_x08; DIP-16_W7.62mm_Socket_LongPads

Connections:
/Alimentazione/+5V: J15.10, RN2.9 (R8.2), RN2.10 (R7.2), RN2.11 (R6.2), RN2.12 (R5.2), RN2.13 (R4.2), RN2.14 (R3.2), RN2.15 (R2.2), RN2.16 (R1.2); also elsewhere on the board
unnamed: J15.2, RN2.1 (R1.1), SW2.16
unnamed: J15.3, RN2.2 (R2.1), SW2.15
unnamed: J15.4, RN2.3 (R3.1), SW2.14
unnamed: J15.5, RN2.4 (R4.1), SW2.13
unnamed: J15.6, RN2.5 (R5.1), SW2.12
unnamed: J15.7, RN2.6 (R6.1), SW2.11
unnamed: J15.8, RN2.7 (R7.1), SW2.10
unnamed: J15.9, RN2.8 (R8.1), SW2.9

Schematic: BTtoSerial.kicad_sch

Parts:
J34: Conn_01x05; PinHeader_1x05_P2.54mm_Vertical
Q7, Q8: BS170; TO-92_Inline
R32, R33, R34, R35: 10K; R_Axial_DIN0207_L6.3mm_D2.5mm_P10.16mm_Horizontal
U12: HC-05 (ZC142200); HC-05 Module Horizontal (ZC14200); PARTREV N/A

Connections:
/Alimentazione/+5V: R34.2, R35.2, U12.5 (VCC); also elsewhere on the board
/BT to Serial/+3.3V: Q7.2 (G), Q8.2 (G), R32.2, R33.2
unnamed: J34.2, Q7.1 (D), R34.1
unnamed: J34.3, Q8.1 (D), R35.1
unnamed: J34.4, U12.6 (EN)
unnamed: J34.5, U12.1 (STATE)
unnamed: Q7.3 (S), R32.1, U12.2 (RX)
unnamed: Q8.3 (S), R33.1, U12.3 (TX)

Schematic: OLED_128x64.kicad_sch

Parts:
J21: Gnd SCL SDA; PinHeader_1x03_P2.54mm_Vertical
LCD1: SSD1306_OLED128x64_I2C; TFT OLED 1.3 I2C
R3, R25: 3,3k; R_Axial_DIN0207_L6.3mm_D2.5mm_P10.16mm_Horizontal

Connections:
/Alimentazione/+5V: LCD1.1 (Vcc), R3.2, R25.2; also elsewhere on the board
unnamed: J21.2, LCD1.3 (SCL), R3.1
unnamed: J21.3, LCD1.4 (SDA), R25.1

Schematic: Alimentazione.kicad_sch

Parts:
C1: 1000uF; CP_Radial_D17.0mm_P7.50mm
C2, C3, C5, C16, C23, C24: 100nF; C_Disc_D7.0mm_W2.5mm_P5.00mm
C4: 10uF; CP_Radial_D5.0mm_P2.00mm
C6, C7, C25: 220uF; CP_Radial_D10.0mm_P5.00mm
D1: D_Bridge_+AA-; Diode_Bridge_Vishay_KBL
D2: VarOut; LED_D5.0mm
D3, D5: 1n4001; D_A-405_P10.16mm_Horizontal
D4, D20: 1N4001; D_A-405_P10.16mm_Horizontal
D21: +5V; LED_D5.0mm
D22: +3.3V; LED_D5.0mm
F1: Polyfuse 750mA; RV_Disc_D7mm_W5.4mm_P5mm
HS1, HS2: Heatsink; Heatsink_28x25_Horiz
J4: Barrel_Jack_MountingPin; BarrelJack_Horizontal
J5, J29, J30: Conn_01x02_Male; PinSocket_1x02_P2.54mm_Vertical
L1: 3,3mH; L_Axial_L12.0mm_D5.0mm_P15.24mm_Horizontal_Fastron_MISC
Q5: BC237; TO-92_Inline
R1: 3,3k; R_Axial_DIN0207_L6.3mm_D2.5mm_P10.16mm_Horizontal
R2: 240; R_Axial_DIN0207_L6.3mm_D2.5mm_P10.16mm_Horizontal
R22: 330k; R_Axial_DIN0207_L6.3mm_D2.5mm_P10.16mm_Horizontal
R23: 680; R_Axial_DIN0207_L6.3mm_D2.5mm_P10.16mm_Horizontal
R24: 220; R_Axial_DIN0207_L6.3mm_D2.5mm_P10.16mm_Horizontal
RV2: 5K; Potentiometer_Omeg_PC16BU_Vertical
SW1: SwGenerale; SW_100SP1T2B4M7QE
TP14: VarA+; TestPoint_Loop_D3.80mm_Drill2.8mm
TP15: VarA-; TestPoint_Loop_D3.80mm_Drill2.8mm
TP16: 5VA+; TestPoint_Loop_D3.80mm_Drill2.8mm
TP17: 3.3VA+; TestPoint_Loop_D3.80mm_Drill2.8mm
TP18: 5VA-; TestPoint_Loop_D3.80mm_Drill2.8mm
TP19: 3.3VA-; TestPoint_Loop_D3.80mm_Drill2.8mm
U1: LM317_TO-220; TO-220-3_Horizontal_TabDown
U2: LM7805_TO220; TO-220-3_Horizontal_TabDown
U11: L78L33_SOT89; SOT-223
Vmet1: 3,5_Digit_Voltmeter_3Wire; 3,5 Digit 0,28'' Voltmeter

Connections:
/Alimentazione/+3.3V: J30.2, R24.1, TP19.1; also elsewhere on the board
/Alimentazione/+5V: J29.2, R23.1, TP18.1; also elsewhere on the board
/Alimentazione/+Vvar: C23.1, J5.2, R22.2, TP15.1, Vmet1.2 (Vin); also elsewhere on the board
unnamed: C1.1, C2.1, C3.1, D3.1 (K), D4.1 (K), L1.2, R1.1, U1.3 (VI), U2.1 (VI)
unnamed: C4.1, D5.2 (A), R2.2, RV2.1, U1.1 (ADJ)
unnamed: C7.1, D3.2 (A), D5.1 (K), J5.1, R2.1, TP14.1, U1.2 (VO)
unnamed: C5.1, C6.1, C16.1, D4.2 (A), D20.1 (K), J29.1, TP16.1, U2.3 (VO), U11.3 (IN), Vmet1.3 (V+)
unnamed: C24.1, C25.1, D20.2 (A), J30.1, TP17.1, U11.1 (OUT)
unnamed: D1.1 (+), L1.1
unnamed: D1.2, F1.2
unnamed: D1.3, SW1.3 (C)
unnamed: D2.1 (K), Q5.1 (C)
unnamed: D2.2 (A), R1.2
unnamed: D21.2 (A), R23.2
unnamed: D22.2 (A), R24.2
unnamed: F1.1, J4.1
unnamed: J4.2, SW1.2 (B)
unnamed: Q5.2 (B), R22.1

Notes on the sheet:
MountingHole:Asola

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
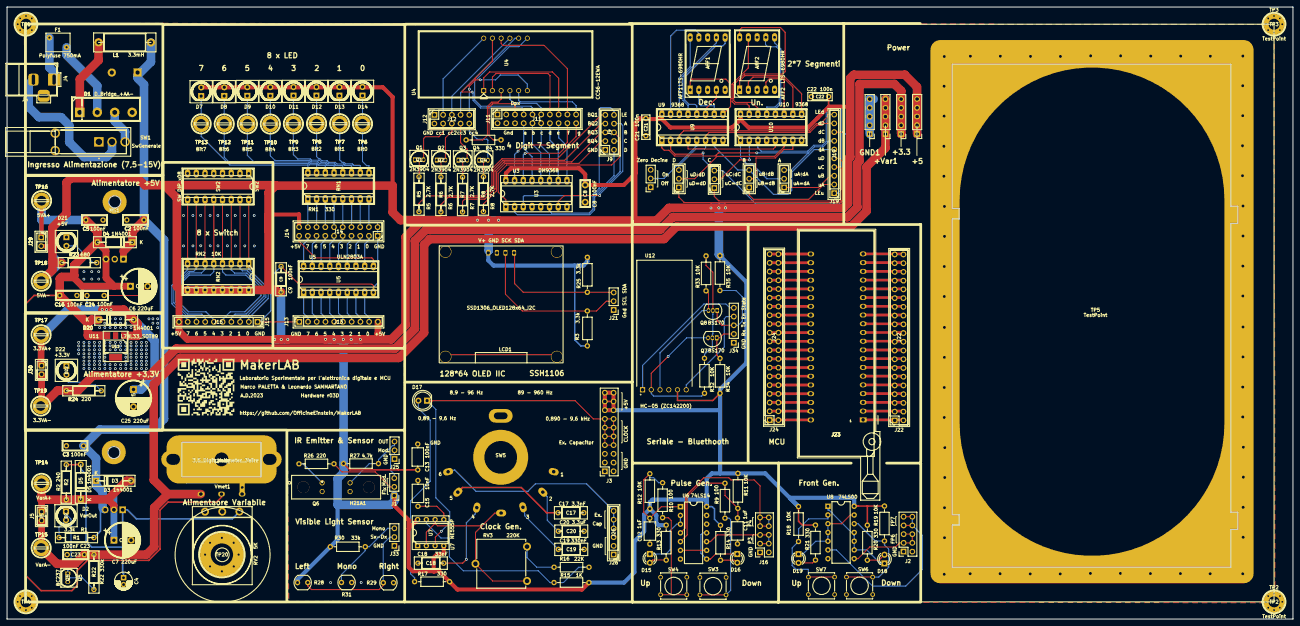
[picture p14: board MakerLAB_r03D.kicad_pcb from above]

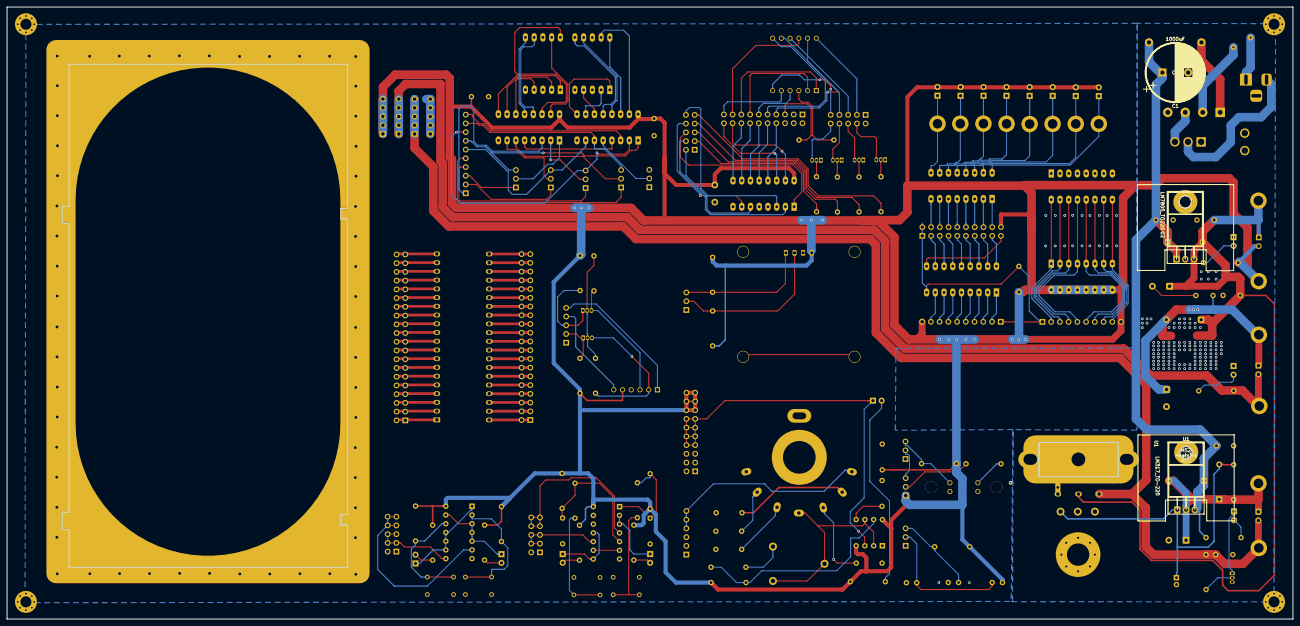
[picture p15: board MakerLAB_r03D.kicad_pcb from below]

Board: 2 copper layers, 374.0 x 178.0 mm, 183 parts (5 on the bottom side), 212 nets.

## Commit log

2023-03-09 20230309-Update
    Lavoro in tandem con Marco
    [Alimentazione.kicad_sch, Gen_Clock.kicad_sch, Input_8bit.kicad_sch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]
2023-03-15 Power Unit
    Iniziato a sistemare l'unità alimentatore
    [Alimentazione.kicad_sch, MakerLAB_r03.kicad_pcb, MakerLAB_r03.kicad_sch]
2023-03-16 Power Supply
    Seconda fase
    [Alimentazione.kicad_sch, MakerLAB_r03.kicad_pcb, MakerLAB_r03.kicad_sch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]
2023-03-20 Layout Alimentatori OK
    [Alimentazione.kicad_sch, MakerLAB_r03.kicad_pcb, MakerLAB_r03.kicad_sch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]
2023-03-20 Bozza con LCD 16x2
    [MakerLAB_r03.kicad_pcb, MakerLAB_r03.kicad_sch]
2023-03-21 test Ma<rco
    [Alimentazione-Maker-2.kicad_sch, MakerLAB_r03-Maker-2.kicad_pcb, MakerLAB_r03-Maker-2.kicad_sch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]
2023-03-21 Up a Scuola del 21
    [AlimVar.kicad_sch, Alimentazione.kicad_sch, Gen_Clock.kicad_sch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]
2023-03-27 27 notte
    [MakerLAB_r03A.kicad_pcb, MakerLAB_r03A.kicad_sch, OLED_128x64.kicad_sch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]
2023-03-28 20230328-13
    20230328-13
    [BTtoSerial.kicad_sch, IRSensor.kicad_sch, MakerLAB_r03A.kicad_pcb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]
2023-03-28 Born r03B
    [AlimVar.kicad_sch, Alimentazione.kicad_sch, BTtoSerial.kicad_sch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]
2023-03-28 versione r03B della notte del 28 marzo 2023
    [AlimVar.kicad_sch, Alimentazione-Maker-2.kicad_sch, Alimentazione.kicad_sch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]
2023-03-28 Aggiornamento Foto di copertina
2023-03-28 e la foto di copertina ridimensionata
2023-04-03 20230403 - Routing in corso
    [MakerLAB_r03C.dsn, MakerLAB_r03C.kicad_pcb]
2023-04-03 20230403 17:12
    [MakerLAB_r03C.kicad_pcb]
2023-04-04 20230404 2:20
    [MakerLAB_r03C.kicad_pcb, MakerLAB_r03C.kicad_sch, Visual_4Dgt.kicad_sch]
2023-04-04 20230404 14:30
    [Gen_Clock.kicad_sch, MakerLAB_r03C.kicad_pcb, MakerLAB_r03C.kicad_sch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]
2023-04-04 Routing e Zone OK
    [MakerLAB_r03C.kicad_pcb, MakerLAB_r03C.kicad_sch, PadSerigrafie.kicad_sch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]
2023-04-04 test schematic scritte
    [MakerLAB_r03C.kicad_sch, Visual_4Dgt.kicad_sch]
2023-04-04 visual 4 dgt scritte
    [MakerLAB_r03C.kicad_sch, Visual_4Dgt.kicad_sch]
2023-04-04 4 DGT SCRITTE 2
    [MakerLAB_r03C.kicad_sch, Visual_4Dgt.kicad_sch]
2023-04-04 Up Serigrafie
    [MakerLAB_r03C.kicad_pcb]
2023-04-05 SCHEMI CONN ANNOTATI
    CONNETTORI ANNOTATI 5.4.23
    [Gen_Clock.kicad_sch, Gen_Fronti_sch.kicad_sch, MakerLAB_r03C.kicad_sch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]
2023-04-20 Sub r03D
    Subver per completamento grafica del PCB
    [AlimVar.kicad_sch, Alimentazione.kicad_sch, BTtoSerial.kicad_sch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]
2023-04-21 Versione D prima del controllo di fine sessione
    [MakerLAB_r03D.kicad_pcb, MakerLAB_r03D.kicad_sch, Visual_8Led.kicad_sch]
2023-04-21 Fine Controllo
    [MakerLAB_r03D.kicad_pcb]
2023-04-27 Ultima prima del logo
    [MakerLAB_r03D.kicad_pcb]
2023-04-27 Con Supporto Breadboard
    [AlimVar.kicad_sch, Alimentazione.kicad_sch, BTtoSerial.kicad_sch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]
2023-04-27 Versione finale, aprile 2023
    Demo Board in produzione.
2023-04-27 28-4-2023
    Demo Board in produzione

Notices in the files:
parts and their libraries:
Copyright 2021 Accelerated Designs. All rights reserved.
